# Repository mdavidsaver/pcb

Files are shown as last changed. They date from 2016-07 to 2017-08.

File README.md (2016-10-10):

Arduino Shield w/ iCE40 FPGA
============================

State: Development

ice40 chip used with 3.3V I/O pins and 1.2V core.
Chip is *not* 5V tolerant.

The logic level shifter chips have both 5V and 3.3V.
The TI 74LVC chips require that VCCA by power up
before, or with, VCCB.

All level shifters VCCA==3.3, VCCB==5

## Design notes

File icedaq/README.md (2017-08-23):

iceDAQ
======

Spec.

* 2x DAC
* 2x ADC
* 4x DIO
* SPI interface to controller
* Raspberry Pi Hat
* iCE40 FPGA

Connections to iCE40 FPGA
-------------------------

Programming interface for iCE40 is attached to SPI1 of CPU.  Low speed SPI1 used to configure FPGA, and for debugging of primary interface.  Uses SPI1_CE2 pin to simplify layout.

iCE40 reset and configuration done connected to GPIO pins.

Application program uses SPI0 of CPU to arbitrary I/O pins of iCE40.  Use SPI0_CE0.

i2c eeprom for rpi hat discovery.

Route global clocks 0 and 1 from CPU to iCE40 global inputs

External crystal oscillator connected to iCE40 global input.

Break out UART0 for no particular reason.

Additional SPI connections to 2x ADC and 2x DAC chips.

Break out 4x GPIO pins to header

Analog output
-------------

Use 2x TI DACx311 series SPI DAC.

Operate w/ 3.3V supply.  Could use 5V supply directly as SPI is MOSI only.

output into opamp in non-inverting topology.  Gain=1.5 gives output range of 0-5V from 0-3.3V input.

opamp output has space for series and ground termination.

Analog input
------------

Use 3x TI ADC082S021 (50 KS/S -> 200 KS/S) two channel ADC.  Only one channel per chip used.

Operate w/ 3.3V supply.

input from opamp in non-inverting topology through 0.66 resistor divider (5V -> 3.3V).
opamp gain=1.

input of opamp has space for series and ground termination, also option of AC coupling w/ resistor bias network.

Op Amp
------

Microchip MCP6001 quad rail-to-rail opamp.

Operate w/ 5V supply.

Power budget
------------

Maximum current consumption

3.3V

* iCE40

  <8mA per I/O driver

* eeprom Microchip 24LC23

  <3mA

* 2x DACx311

  short circuit output current @3V = 20mA, @5V = 50mA.

* 2x ADC

  <20mA

* oscillator
* 1.2V regulator

5V

* opamp MCP6001

  <=30 mA
  short circuit output current @1.8V = 6mA, @5.5V = 23 mA

1.2V

* iCE40

  <1mA continuous
  <20mA peak startup

Safety
------

MCP6001 outputs may be shorted w/o damage.  input voltage must be within 1V of supply range.

References
----------

Raspberry Pi

https://github.com/raspberrypi/hats/blob/master/designguide.md

https://pinout.xyz/

https://www.raspberrypi.org/documentation/hardware/raspberrypi/schematics/RPI-3B-V1_2-SCHEMATIC-REDUCED.pdf

iCE40

http://www.latticesemi.com/~/media/LatticeSemi/Documents/Handbooks/iCE40FamilyHandbook.pdf

ADC

http://www.ti.com/lit/ds/symlink/adc082s021.pdf

DAC

http://www.ti.com/lit/ds/symlink/dac5311.pdf

opamp

http://ww1.microchip.com/downloads/en/DeviceDoc/21733j.pdf

eeprom

http://ww1.microchip.com/downloads/en/DeviceDoc/21072G.pdf

iCE40 pins
----------

set_io	GPIO2[0]	1
set_io	GPIO2[1]	2
set_io	GPIO2[2]	3
set_io	GPIO2[3]	4
set_io	GPIO3[0]	18
set_io	GPIO3[1]	19
set_io	GPIO3[2]	20
set_io	GPIO3[3]	21
set_io	GPIO0[3]	27
set_io	GPIO0[2]	28
set_io	GPIO0[1]	29
set_io	GPIO0[0]	30
set_io	GCLK0	33
set_io	GCLK1	34
set_io	SPI1_MISO	45
set_io	SPI1_MOSI	46
set_io	SPI1_SCK	48
set_io	SPI1_CE2	49
set_io	SPI0_CE0	51
set_io	SPI0_SCLK	52
set_io	SPI0_MISO	53
set_io	SPI0_MOSI	54
set_io	ADC0_CE	56
set_io	ADC0_SCK	57
set_io	ADC0_MISO	59
set_io	ADC0_MOSI	60
set_io	ADC1_CE	64
set_io	ADC1_SCK	65
set_io	ADC1_MISO	66
set_io	ADC1_MOSI	68
set_io	DAC0_MOSI	78
set_io	DAC0_SCK	79
set_io	DAC0_SYNC	80
set_io	DAC1_MOSI	82
set_io	DAC1_SCK	83
set_io	DAC1_SYNC	85
set_io	CLK	90

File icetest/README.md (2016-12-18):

Arduino Shield w/ iCE40 FPGA
============================

State: Rev 2 tested

[Firmware](https://github.com/mdavidsaver/fpga/tree/master/top/icetest_r2)
[Software](https://github.com/mdavidsaver/fpga/tree/master/avr)

Erratta for rev. 2

* Add pull-up on SS
* LP filter/ isolation on SPI line (noticable cross-talk)

ice40 chip used with 3.3V I/O pins and 1.2V core.
Chip is *not* 5V tolerant.

The logic level shifter chips have both 5V and 3.3V.
The TI 74LVC chips require that VCCA by power up
before, or with, VCCB.

All level shifters VCCA==3.3, VCCB==5

Strictly speaking level shifters not needed for 3.3V -> 5V.

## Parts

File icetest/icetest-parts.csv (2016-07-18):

Comment | Manufacturer | Digikey | Price | Num |  | URL
fpga | ICE40HX1K-VQ100 | 220-1567-ND | $4.95 | 1 | $4.95 | http://www.digikey.com/product-detail/en/lattice-semiconductor-corporation/ICE40HX1K-VQ100/220-1567-ND/3083577
level translate | TXB0108PWR | 296-21527-1-ND | $1.88 | 4 | $7.52 | http://www.digikey.com/product-detail/en/texas-instruments/TXB0108PWR/296-21527-1-ND/1305700
1.2V reg. | NCP585DSN12T1G | NCP585DSN12T1GOSCT-ND | $0.71 | 1 | $0.71 | http://www.digikey.com/product-detail/en/on-semiconductor/NCP585DSN12T1G/NCP585DSN12T1GOSCT-ND/822802
3.3V reg. | AP2112K-3.3TRG1 | AP2112K-3.3TRG1DICT-ND | $0.48 | 1 | $0.48 | http://www.digikey.com/product-detail/en/diodes-incorporated/AP2112K-3.3TRG1/AP2112K-3.3TRG1DICT-ND/4505257
20V shottky diode | CDBU0520 | 641-1332-1-ND | $0.47 | 1 | $0.47 | http://www.digikey.com/product-detail/en/comchip-technology/CDBU0520/641-1332-1-ND/2021253
12MHz Osc. | 636L3C012M00000 | CTX1006CT-ND | $1.37 | 1 | $1.37 | http://www.digikey.com/product-detail/en/cts-frequency-controls/636L3C012M00000/CTX1006CT-ND/2640344
 |  |  |  |  | $15.50

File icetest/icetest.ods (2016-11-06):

Comment | Manufacturer | Digikey | Price | Num |  | URL
fpga | ICE40HX1K-VQ100 | 220-1567-ND | $4.95 | 1 | $4.95 | http://www.digikey.com/product-detail/en/lattice-semiconductor-corporation/ICE40HX1K-VQ100/220-1567-ND/3083577
level translate | SN74LVC2T45 | 568-5479-1-ND | $0.58 | 8 | $4.64 | http://www.nxp.com/documents/data_sheet/74LVC_LVCH2T45.pdf
level translate | TXB0108PWR | 296-21527-1-ND | $1.80 | 0 | $0.00 | http://www.digikey.com/product-detail/en/texas-instruments/TXB0108PWR/296-21527-1-ND/1305700
1.2V reg. | NCP585DSN12T1G | NCP585DSN12T1GOSCT-ND | $0.71 | 1 | $0.71 | http://www.digikey.com/product-detail/en/on-semiconductor/NCP585DSN12T1G/NCP585DSN12T1GOSCT-ND/822802
3.3V reg. | AP2112K-3.3TRG1 | AP2112K-3.3TRG1DICT-ND | $0.48 | 1 | $0.48 | http://www.digikey.com/product-detail/en/diodes-incorporated/AP2112K-3.3TRG1/AP2112K-3.3TRG1DICT-ND/4505257
20V shottky diode | CDBU0520 | 641-1332-1-ND | $0.47 | 1 | $0.47 | http://www.digikey.com/product-detail/en/comchip-technology/CDBU0520/641-1332-1-ND/2021253
12MHz Osc. | 636L3C012M00000 | CTX1006CT-ND | $1.37 | 1 | $1.37 | http://www.digikey.com/product-detail/en/cts-frequency-controls/636L3C012M00000/CTX1006CT-ND/2640344
22 ohm resitor |  |  | $0.01 | 6 | $0.06
10k resistor | RC0603FR-0710KL | 311-10.0KHRCT-ND | $0.01 | 11 | $0.11 | http://www.digikey.com/product-detail/en/yageo/RC0603FR-0710KL/311-10.0KHRCT-ND/729827
1u cap |  |  | $0.04 | 5 | $0.20
100n cap |  | 490-1519-1-ND | $0.04 | 16 | $0.64 | http://www.digikey.com/product-detail/en/murata-electronics-north-america/GRM188R71H104KA93D/490-1519-1-ND/587854
LED |  |  | $0.10 | 2 | $0.20
Pin header 0.1mil |  |  |  | 96 | $0.00
 |  |  |  |  | $12.62

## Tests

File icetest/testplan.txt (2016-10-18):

* Populate 1.2v and 3.3v regulators and test w/ standalone 5v supply.
  * All voltages accessible from top side

* Populate UL1, 2, and 3 and test level shifting
  * Test pads for all 6 control lines

* Populate ICE1 and test bit stream load
  * AVR program to load via. SPI
  * .v to loop back MOSI to MISO and D9 to D8 (RST -> CDONE)

* Populate OSC1 and check frequency
  * copy OSC1 to output pin(s)

* Populate LEDs, UL4 and test
  * copy D5,6 to LED outputs, drive with AVR PWM

* Populate UL5, 6, 7, 8 and test 5V from ICE1
  * copy D5,6 to outputs

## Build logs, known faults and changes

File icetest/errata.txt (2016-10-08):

rev1 issues

* Need 1.2V test points on top side.
* Would be good to mark ARD pins on top side.

* bus transceiver not working so easily.  Probably needed to put pull ups on driving side...

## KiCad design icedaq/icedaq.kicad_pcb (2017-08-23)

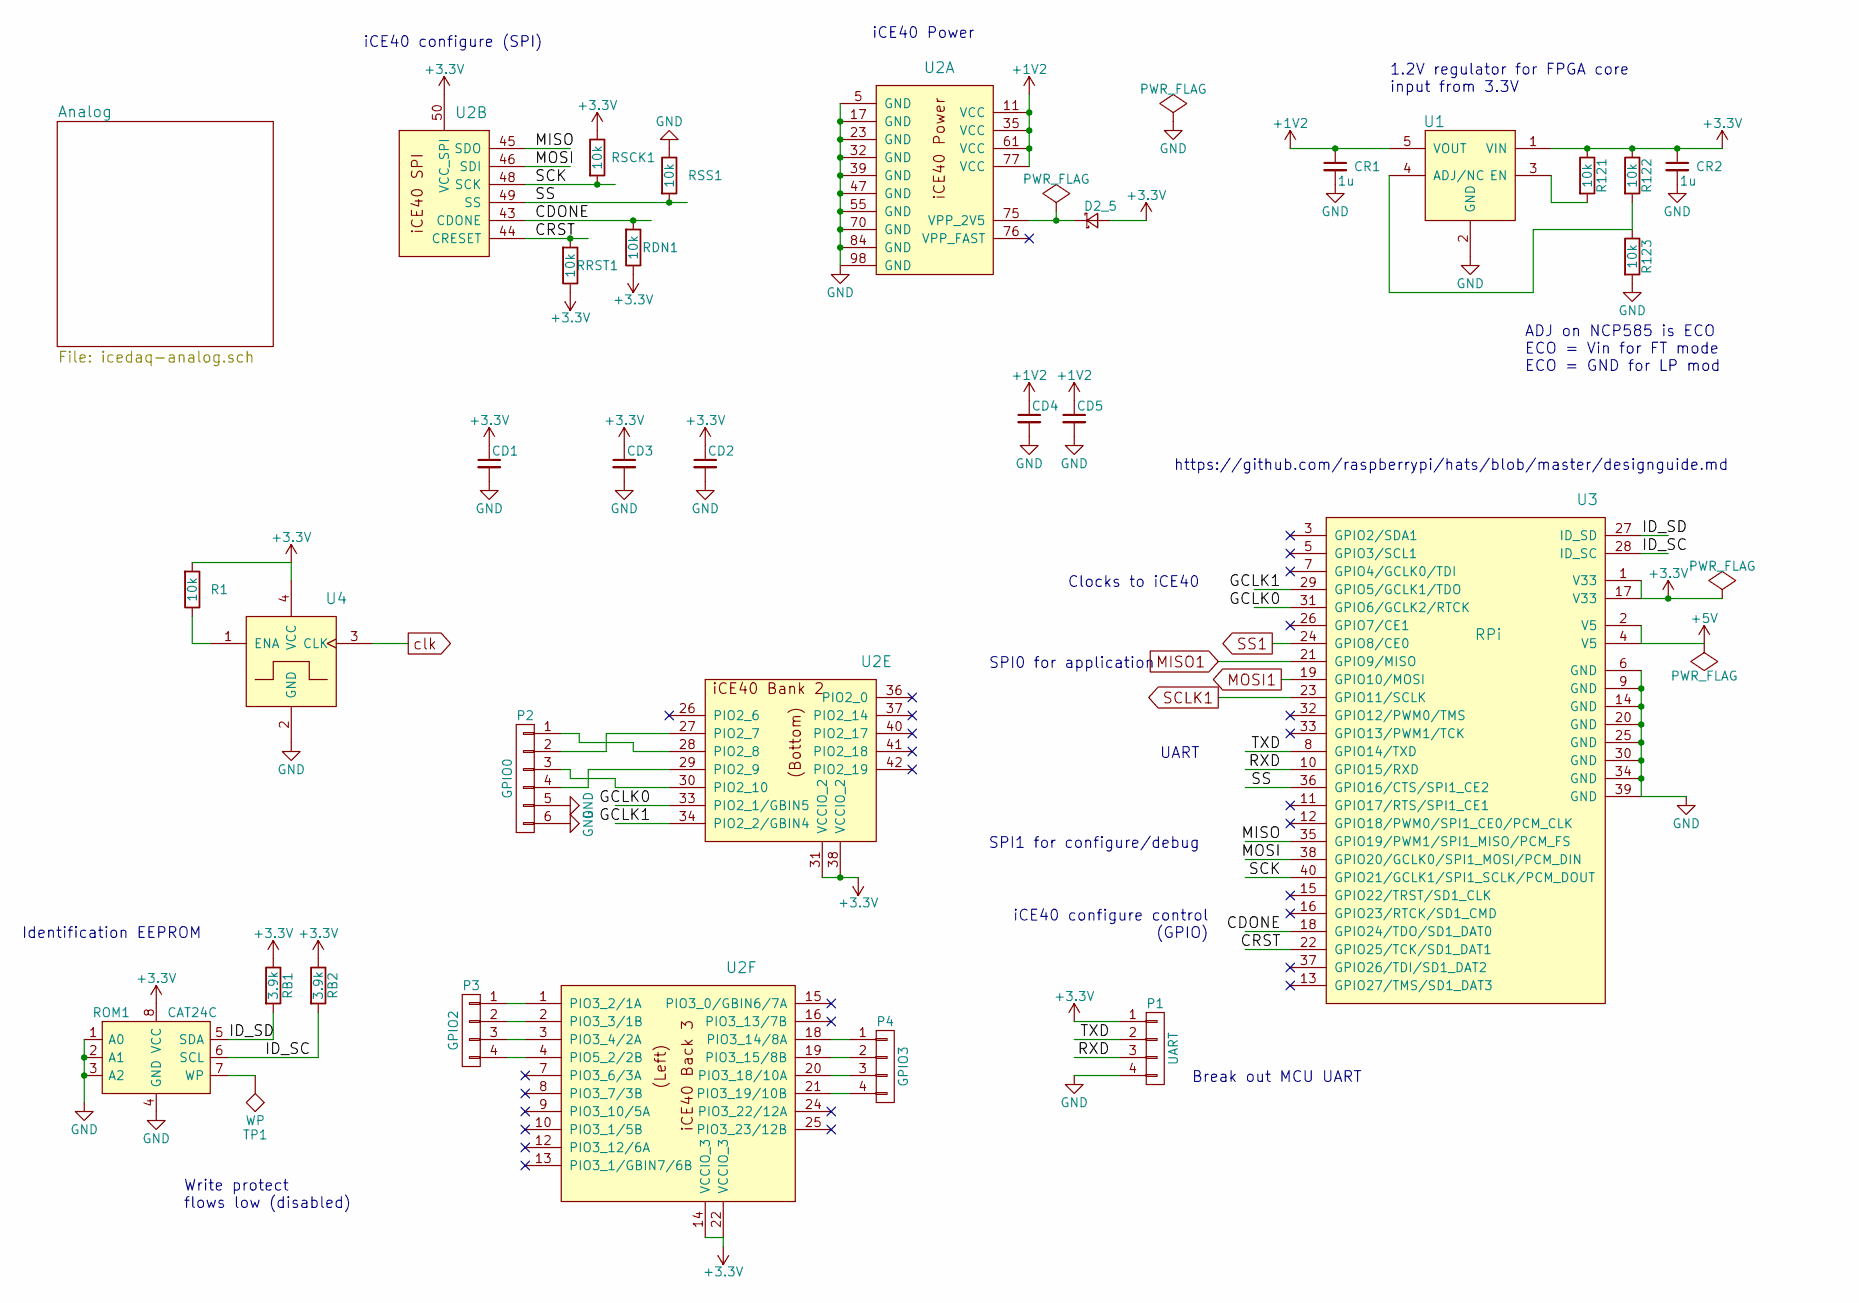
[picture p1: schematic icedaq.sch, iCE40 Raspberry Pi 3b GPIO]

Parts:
CD1, CD2, CD3, CD4, CD5: C_Small; C_0603_HandSoldering
CR1, CR2: 1u; C_0603_HandSoldering
D2_5: D_Schottky_Small; D_0603_HandSoldering
P1: UART; Pin_Header_Straight_1x04
P2: GPIO0; Pin_Header_Straight_2x03
P3: GPIO2; gpio
P4: GPIO3; gpio
R1, R121, R122, R123: 10k; R_0603_HandSoldering
RB1, RB2: 3.9k; R_0603_HandSoldering
RDN1: 10k; R_0603_HandSoldering
ROM1: CAT24C; SOIC-8_3.9x4.9mm_Pitch1.27mm
RRST1: 10k; R_0603_HandSoldering
RSCK1: 10k; R_0603_HandSoldering
RSS1: 10k; R_0603_HandSoldering
TP1: WP; testpoint
U1: REG12; SOT23-5
U2: iCE40HX1K-VQ100; VQFP-100
U3: RPi; Pin_Header_Straight_2x20
U4: oscillator4; OSC_SMD_1

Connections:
+1V2: CD4.1, CD5.1, CR1.1, U1.5 (VOUT), U2.11 (VCC), U2.35 (VCC), U2.61 (VCC), U2.77 (VCC)
+3V3: CD1.1, CD2.1, CD3.1, CR2.1, D2_5.2 (A), P1.1, R1.2, R121.1, R122.1, RB1.1, RB2.1, RDN1.1, ROM1.8 (VCC), RRST1.1, RSCK1.1, U1.1 (VIN), U2.14 (VCCIO_3), U2.22 (VCCIO_3), U2.31 (VCCIO_2), U2.38 (VCCIO_2), U2.50 (VCC_SPI), U3.1 (V33), U3.17 (V33), U4.4 (VCC); also elsewhere on the board
+5V: U3.2 (V5), U3.4 (V5); also elsewhere on the board
/CDONE: RDN1.2, U2.43 (CDONE), U3.18 (GPIO24/TDO/SD1_DAT0)
/CRST: RRST1.2, U2.44 (CRESET), U3.22 (GPIO25/TCK/SD1_DAT1)
/GCLK0: U2.33 (PIO2_1/GBIN5), U3.31 (GPIO6/GCLK2/RTCK)
/GCLK1: U2.34 (PIO2_2/GBIN4), U3.29 (GPIO5/GCLK1/TDO)
/ID_SC: RB2.2, ROM1.6 (SCL), U3.28 (ID_SC)
/ID_SD: RB1.2, ROM1.5 (SDA), U3.27 (ID_SD)
/MISO: U2.45 (SDO), U3.35 (GPIO19/PWM1/SPI1_MISO/PCM_FS)
/MOSI: U2.46 (SDI), U3.38 (GPIO20/GCLK0/SPI1_MOSI/PCM_DIN)
/RXD: P1.3, U3.10 (GPIO15/RXD)
/SCK: RSCK1.2, U2.48 (SCK), U3.40 (GPIO21/GCLK1/SPI1_SCLK/PCM_DOUT)
/SS: RSS1.2, U2.49 (SS), U3.36 (GPIO16/CTS/SPI1_CE2)
/TXD: P1.2, U3.8 (GPIO14/TXD)
GND: CD1.2, CD2.2, CD3.2, CD4.2, CD5.2, CR1.2, CR2.2, P1.4, P2.5, P2.6, R123.2, ROM1.1 (A0), ROM1.2 (A1), ROM1.3 (A2), ROM1.4 (GND), RSS1.1, U1.2 (GND), U2.5 (GND), U2.17 (GND), U2.23 (GND), U2.32 (GND), U2.39 (GND), U2.47 (GND), U2.55 (GND), U2.70 (GND), U2.84 (GND), U2.98 (GND), U3.6 (GND), U3.9 (GND), U3.14 (GND), U3.20 (GND), U3.25 (GND), U3.30 (GND), U3.34 (GND), U3.39 (GND), U4.2 (GND); also elsewhere on the board
MISO1: U3.21 (GPIO9/MISO); also elsewhere on the board
MOSI1: U3.19 (GPIO10/MOSI); also elsewhere on the board
unnamed: D2_5.1 (K), U2.75 (VPP_2V5)
unnamed: P2.1, U2.28 (PIO2_8)
unnamed: P2.2, U2.27 (PIO2_7)
unnamed: P2.3, U2.30 (PIO2_10)
unnamed: P2.4, U2.29 (PIO2_9)
unnamed: P3.1, U2.1 (PIO3_2/1A)
unnamed: P3.2, U2.2 (PIO3_3/1B)
unnamed: P3.3, U2.3 (PIO3_4/2A)
unnamed: P3.4, U2.4 (PIO5_2/2B)
unnamed: P4.1, U2.18 (PIO3_14/8A)
unnamed: P4.2, U2.19 (PIO3_15/8B)
unnamed: P4.3, U2.20 (PIO3_18/10A)
unnamed: P4.4, U2.21 (PIO3_19/10B)
unnamed: R1.1, U4.1 (ENA)
unnamed: R121.2, U1.3 (EN)
unnamed: R122.2, R123.1, U1.4 (ADJ/NC)
unnamed: ROM1.7 (WP), TP1.1
SCLK1: U3.23 (GPIO11/SCLK); also elsewhere on the board
SS1: U3.24 (GPIO8/CE0); also elsewhere on the board
clk: U4.3 (CLK); also elsewhere on the board

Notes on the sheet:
1.2V regulator for FPGA core input from 3.3V
ADJ on NCP585 is ECO ECO = Vin for FT mode ECO = GND for LP mod
SPI0 for application
SPI1 for configure/debug
iCE40 configure control (GPIO)
UART
Clocks to iCE40
iCE40 Power
iCE40 configure (SPI)
https://github.com/raspberrypi/hats/blob/master/designguide.md
Break out MCU UART
Write protect flows low (disabled)
Identification EEPROM

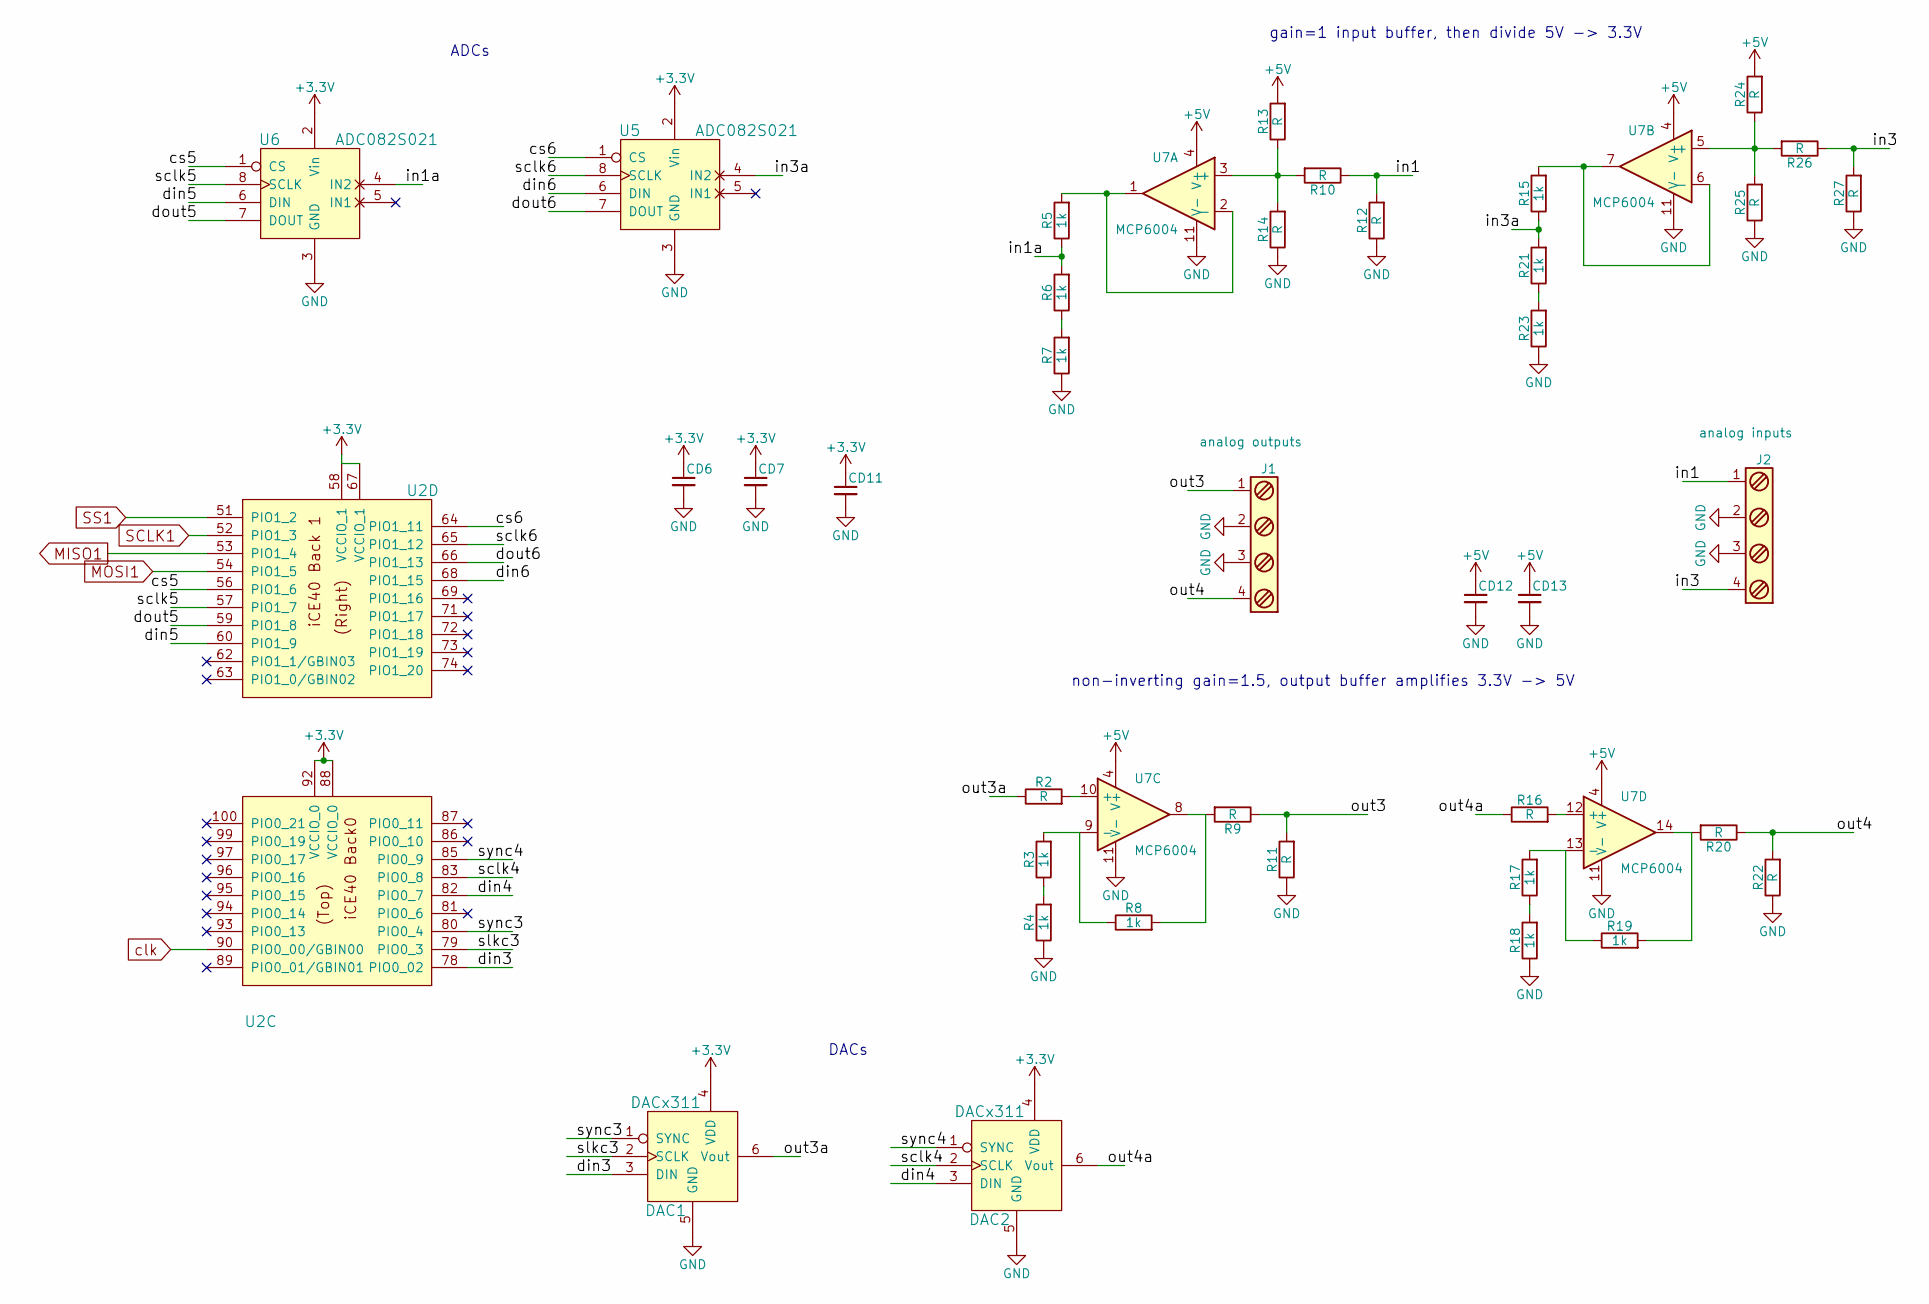
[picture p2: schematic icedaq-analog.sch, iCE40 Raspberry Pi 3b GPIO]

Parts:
CD6, CD7, CD11, CD12, CD13: C_Small; C_0603_HandSoldering
DAC1, DAC2: DACx311; SC70
J1: analog outputs; TerminalBlock_Pheonix_MPT-2.54mm_4pol
J2: analog inputs; TerminalBlock_Pheonix_MPT-2.54mm_4pol
R2, R9, R10, R11, R12, R13, R14, R16, R20, R22, R24, R25, R26, R27: R; R_0603_HandSoldering
R3, R4, R5, R6, R7, R8, R15, R17, R18, R19, R21, R23: 1k; R_0603_HandSoldering
U2: iCE40HX1K-VQ100; VQFP-100
U5, U6: ADC082S021; VSSOP-8
U7: MCP6004; SOIC-14

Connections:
+3V3: CD6.1, CD7.1, CD11.1, DAC1.4 (VDD), DAC2.4 (VDD), U2.58 (VCCIO_1), U2.67 (VCCIO_1), U2.88 (VCCIO_0), U2.92 (VCCIO_0), U5.2 (Vin), U6.2 (Vin); also elsewhere on the board
+5V: CD12.1, CD13.1, R13.2, R24.2, U7.4 (V+); also elsewhere on the board
/Analog/cs5: U2.56 (PIO1_6), U6.1 (CS)
/Analog/cs6: U2.64 (PIO1_11), U5.1 (CS)
/Analog/din3: DAC1.3 (DIN), U2.78 (PIO0_02)
/Analog/din4: DAC2.3 (DIN), U2.82 (PIO0_7)
/Analog/din5: U2.60 (PIO1_9), U6.6 (DIN)
/Analog/din6: U2.68 (PIO1_15), U5.6 (DIN)
/Analog/dout5: U2.59 (PIO1_8), U6.7 (DOUT)
/Analog/dout6: U2.66 (PIO1_13), U5.7 (DOUT)
/Analog/in1: J2.1, R10.1, R12.2
/Analog/in1a: R5.1, R6.2, U6.4 (IN2)
/Analog/in3: J2.4, R26.1, R27.2
/Analog/in3a: R15.1, R21.2, U5.4 (IN2)
/Analog/out3: J1.1, R9.1, R11.2
/Analog/out3a: DAC1.6 (Vout), R2.1
/Analog/out4: J1.4, R20.1, R22.2
/Analog/out4a: DAC2.6 (Vout), R16.1
/Analog/sclk4: DAC2.2 (SCLK), U2.83 (PIO0_8)
/Analog/sclk5: U2.57 (PIO1_7), U6.8 (SCLK)
/Analog/sclk6: U2.65 (PIO1_12), U5.8 (SCLK)
/Analog/slkc3: DAC1.2 (SCLK), U2.79 (PIO0_3)
/Analog/sync3: DAC1.1 (SYNC), U2.80 (PIO0_4)
/Analog/sync4: DAC2.1 (SYNC), U2.85 (PIO0_9)
GND: CD6.2, CD7.2, CD11.2, CD12.2, CD13.2, DAC1.5 (GND), DAC2.5 (GND), J1.2, J1.3, J2.2, J2.3, R4.1, R7.1, R11.1, R12.1, R14.1, R18.1, R22.1, R23.1, R25.1, R27.1, U5.3 (GND), U6.3 (GND), U7.11 (V-); also elsewhere on the board
MISO1: U2.53 (PIO1_4); also elsewhere on the board
MOSI1: U2.54 (PIO1_5); also elsewhere on the board
unnamed: R2.2, U7.10 (+)
unnamed: R3.1, R4.2
unnamed: R3.2, R8.1, U7.9 (-)
unnamed: R5.2, U7.1, U7.2 (-)
unnamed: R6.1, R7.2
unnamed: R8.2, R9.2, U7.8
unnamed: R10.2, R13.1, R14.2, U7.3 (+)
unnamed: R15.2, U7.6 (-), U7.7
unnamed: R16.2, U7.12 (+)
unnamed: R17.1, R18.2
unnamed: R17.2, R19.1, U7.13 (-)
unnamed: R19.2, R20.2, U7.14
unnamed: R21.1, R23.2
unnamed: R24.1, R25.2, R26.2, U7.5 (+)
SCLK1: U2.52 (PIO1_3); also elsewhere on the board
SS1: U2.51 (PIO1_2); also elsewhere on the board
clk: U2.90 (PIO0_00/GBIN00); also elsewhere on the board

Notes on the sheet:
gain=1 input buffer, then divide 5V -> 3.3V
non-inverting gain=1.5, output buffer amplifies 3.3V -> 5V
ADCs
DACs

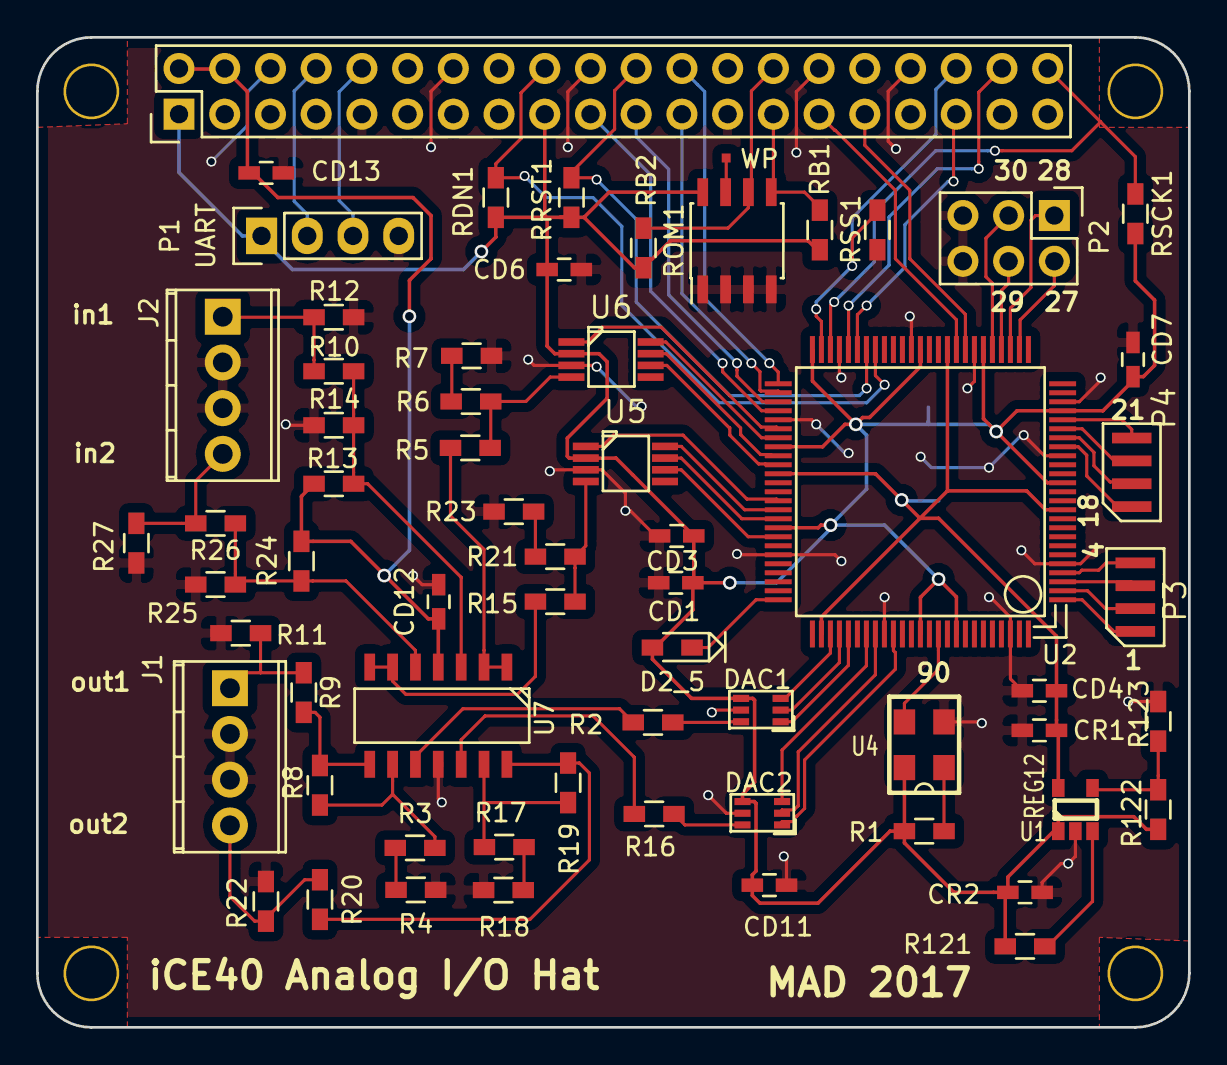
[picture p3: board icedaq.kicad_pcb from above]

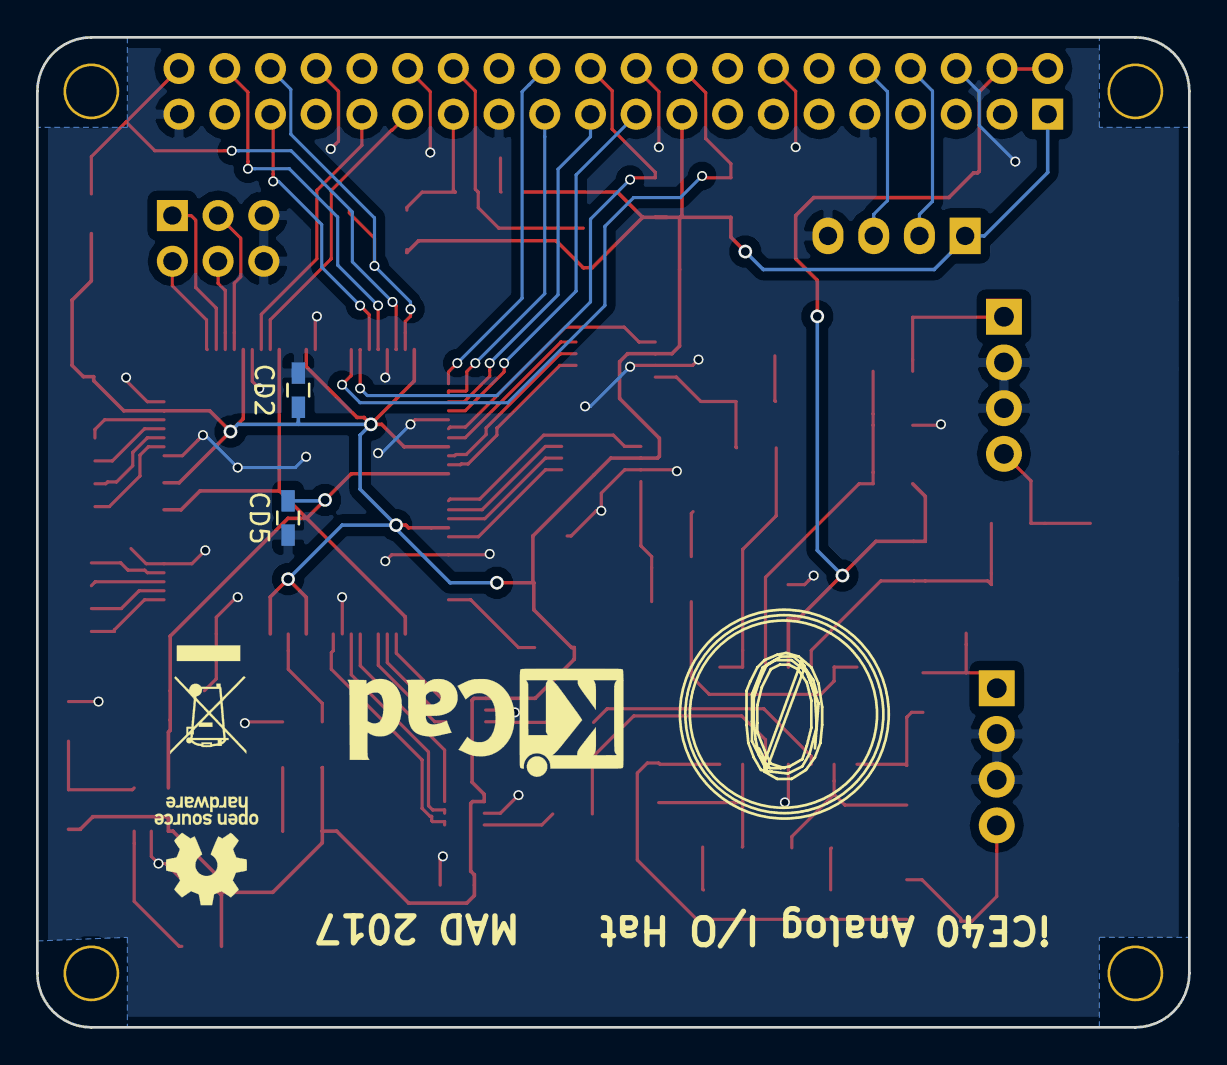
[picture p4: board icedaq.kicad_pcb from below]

Board: 2 copper layers, 64.0 x 55.0 mm, 67 parts (2 on the bottom side), 74 nets.

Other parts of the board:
MNT1: MountingHole_3mm

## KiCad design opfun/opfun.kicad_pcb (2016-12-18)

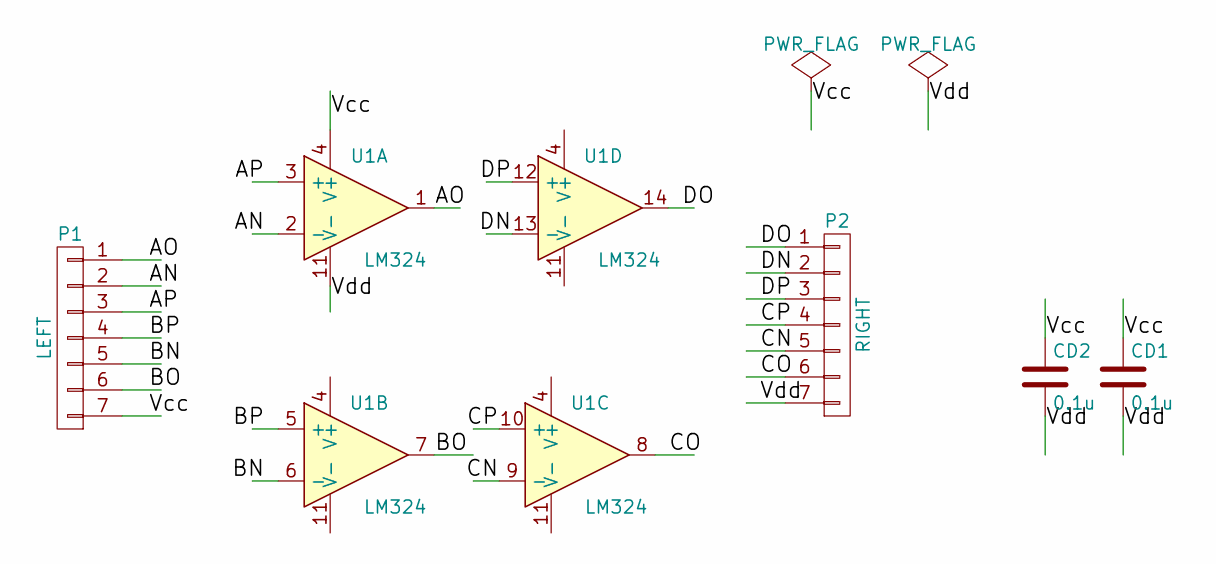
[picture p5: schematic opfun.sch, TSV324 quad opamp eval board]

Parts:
CD1, CD2: 0.1u; C_0603_HandSoldering
P1: LEFT; Pin_Header_Straight_1x07
P2: RIGHT; Pin_Header_Straight_1x07
U1: LM324; TSSOP-14

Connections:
/AN: P1.2, U1.2 (-)
/AO: P1.1, U1.1
/AP: P1.3, U1.3 (+)
/BN: P1.5, U1.6 (-)
/BO: P1.6, U1.7
/BP: P1.4, U1.5 (+)
/CN: P2.5, U1.9 (-)
/CO: P2.6, U1.8
/CP: P2.4, U1.10 (+)
/DN: P2.2, U1.13 (-)
/DO: P2.1, U1.14
/DP: P2.3, U1.12 (+)
/Vcc: CD1.1, CD2.1, P1.7, U1.4 (V+)
/Vdd: CD1.2, CD2.2, P2.7, U1.11 (V-)

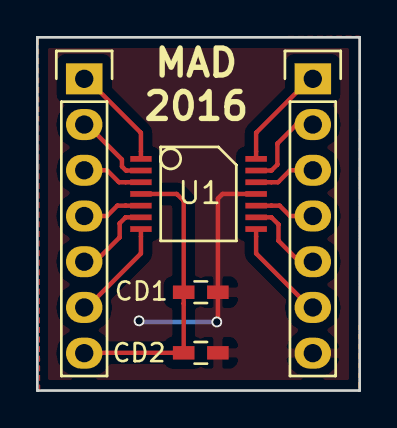
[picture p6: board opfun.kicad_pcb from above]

Board: 2 copper layers, 17.9 x 19.6 mm, 5 parts (0 on the bottom side), 14 nets.

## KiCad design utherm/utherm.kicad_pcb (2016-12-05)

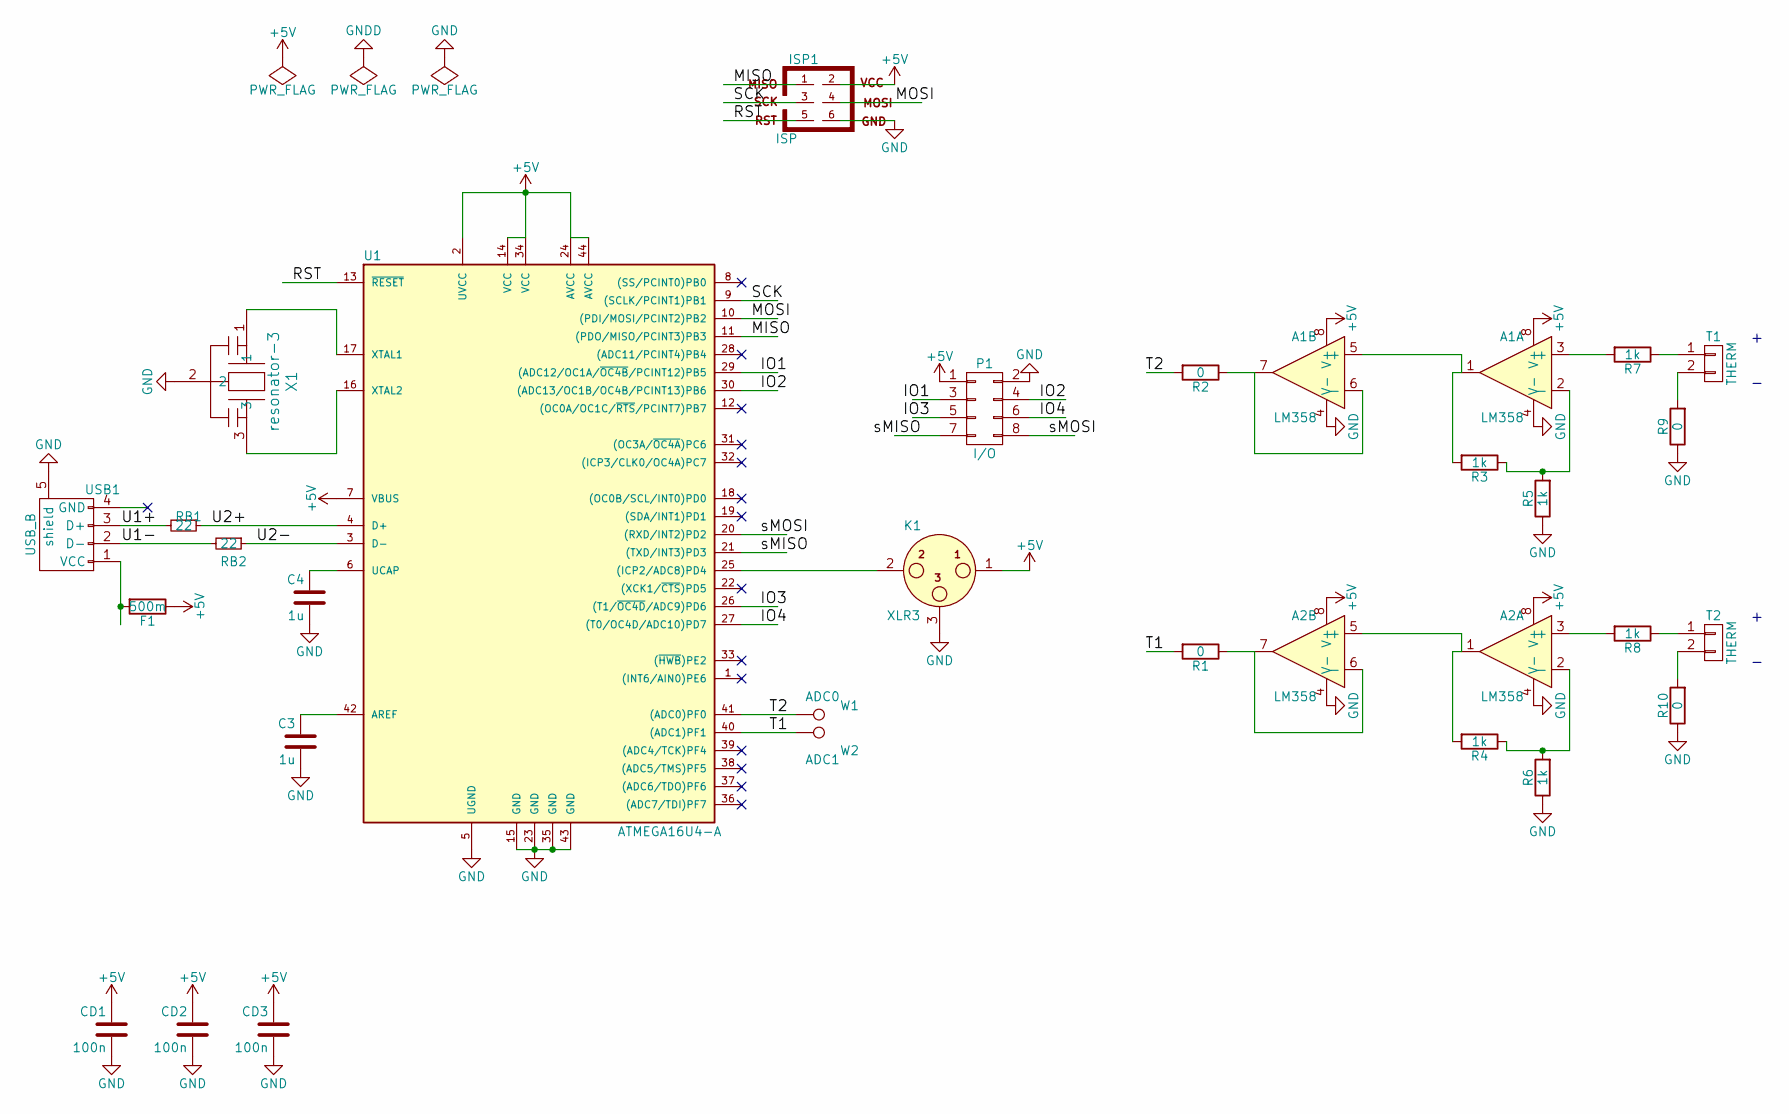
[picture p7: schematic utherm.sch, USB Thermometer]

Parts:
A1, A2: LM358; SO8_6mm
C3, C4: 1u; C_0603_HandSoldering
CD1, CD2, CD3: 100n; C_0603_HandSoldering
F1: 500m; R_1218_HandSoldering
ISP1: ISP; Pin_Header_Straight_2x03
K1: XLR3; TO-92_Molded_Narrow
P1: I/O; Pin_Header_Straight_2x04
R1, R2, R9, R10: 0; R_0603_HandSoldering
R3, R4, R5, R6, R7, R8: 1k; R_0603_HandSoldering
RB1, RB2: 22; R_0603_HandSoldering
T1, T2: THERM; TerminalBlock_Pheonix_MKDS1.5-2pol
U1: ATMEGA16U4-A; TQFP44
USB1: USB_B; USB_B_micro
W1: ADC0; Measurement_Point_Square-SMD-Pad_Small
W2: ADC1; Measurement_Point_Square-SMD-Pad_Small
X1: resonator-3

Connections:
+5V: A1.8 (V+), A2.8 (V+), CD1.1, CD2.1, CD3.1, F1.1, ISP1.2, K1.1, P1.1, U1.2 (UVCC), U1.7 (VBUS), U1.14 (VCC), U1.24 (AVCC), U1.34 (VCC), U1.44 (AVCC)
/IO1: P1.3, U1.29 ((ADC12/OC1A/~OC4B~/PCINT12)PB5)
/IO2: P1.4, U1.30 ((ADC13/OC1B/OC4B/PCINT13)PB6)
/IO3: P1.5, U1.26 ((T1/~OC4D~/ADC9)PD6)
/IO4: P1.6, U1.27 ((T0/OC4D/ADC10)PD7)
/MISO: ISP1.1, U1.11 ((PDO/MISO/PCINT3)PB3)
/MOSI: ISP1.4, U1.10 ((PDI/MOSI/PCINT2)PB2)
/RST: ISP1.5, U1.13 (~RESET~)
/SCK: ISP1.3, U1.9 ((SCLK/PCINT1)PB1)
/T1: R1.2, U1.40 ((ADC1)PF1), W2.1
/T2: R2.2, U1.41 ((ADC0)PF0), W1.1
/U1+: RB1.2, USB1.3 (D+)
/U1-: RB2.2, USB1.2 (D-)
/U2+: RB1.1, U1.4 (D+)
/U2-: RB2.1, U1.3 (D-)
/sMISO: P1.7, U1.21 ((TXD/INT3)PD3)
/sMOSI: P1.8, U1.20 ((RXD/INT2)PD2)
GND: A1.4 (V-), A2.4 (V-), C3.2, C4.2, CD1.2, CD2.2, CD3.2, ISP1.6, K1.3, P1.2, R5.1, R6.1, R9.1, R10.1, U1.5 (UGND), U1.15 (GND), U1.23 (GND), U1.35 (GND), U1.43 (GND), USB1.5 (shield), X1.2
unnamed: A1.1, A1.5 (+), R3.2
unnamed: A1.2 (-), R3.1, R5.2
unnamed: A1.3 (+), R7.2
unnamed: A1.6 (-), A1.7, R2.1
unnamed: A2.1, A2.5 (+), R4.2
unnamed: A2.2 (-), R4.1, R6.2
unnamed: A2.3 (+), R8.2
unnamed: A2.6 (-), A2.7, R1.1
unnamed: C3.1, U1.42 (AREF)
unnamed: C4.1, U1.6 (UCAP)
unnamed: F1.2, USB1.1 (VCC)
unnamed: K1.2, U1.25 ((ICP2/ADC8)PD4)
unnamed: R7.1, T1.1
unnamed: R8.1, T2.1
unnamed: R9.2, T1.2
unnamed: R10.2, T2.2
unnamed: U1.16 (XTAL2), X1.3
unnamed: U1.17 (XTAL1), X1.1

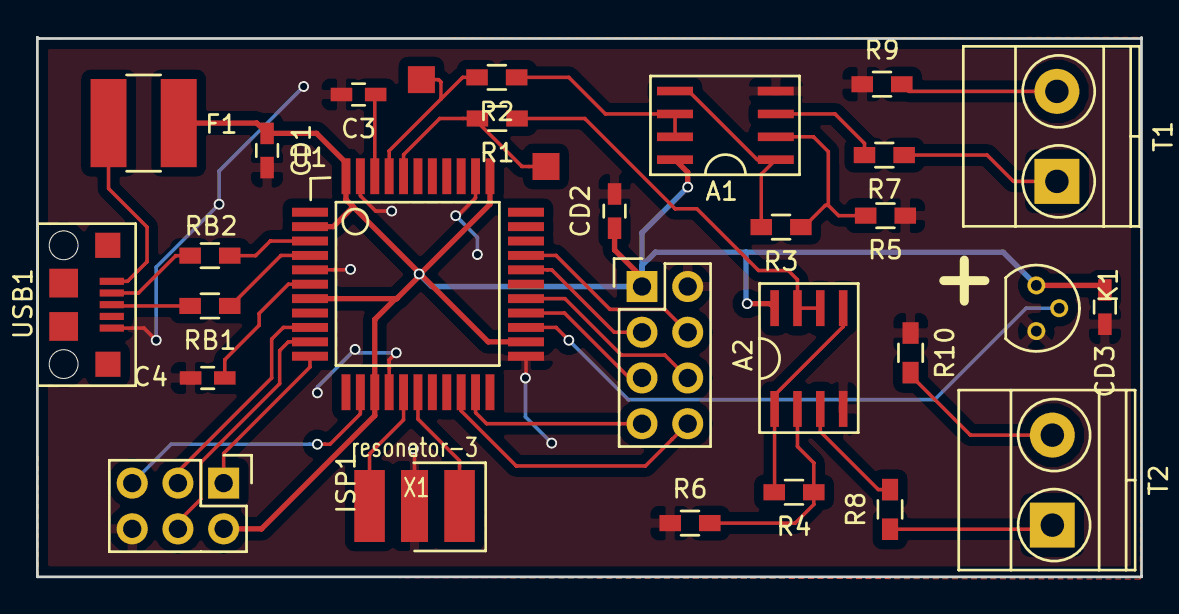
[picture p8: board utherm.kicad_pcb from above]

Board: 2 copper layers, 61.3 x 30.0 mm, 30 parts (0 on the bottom side), 36 nets.

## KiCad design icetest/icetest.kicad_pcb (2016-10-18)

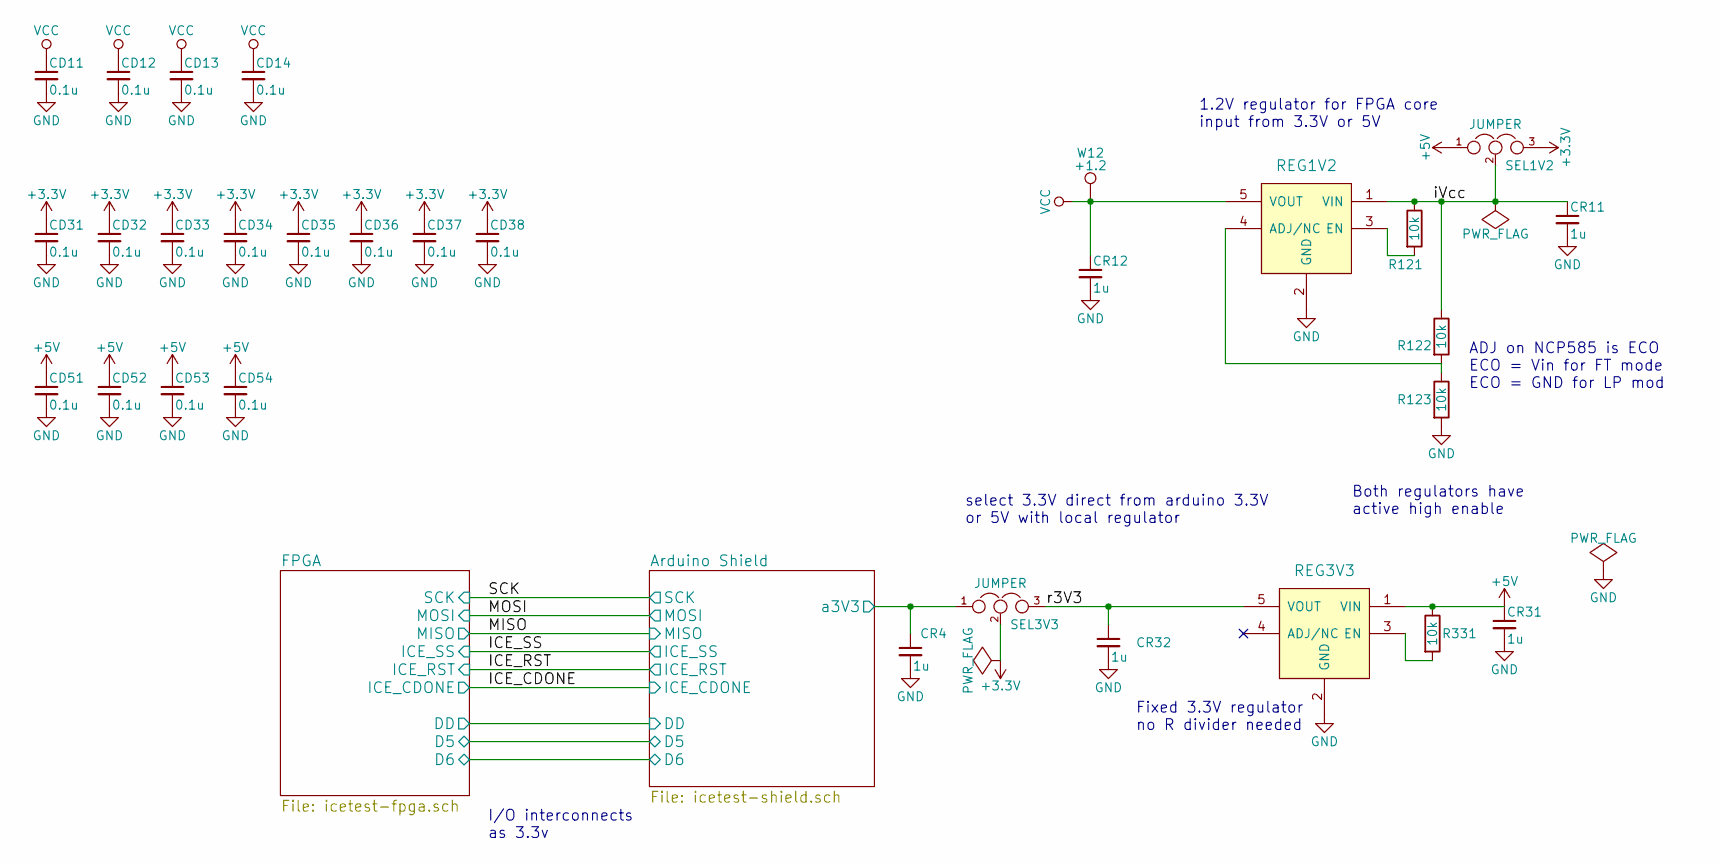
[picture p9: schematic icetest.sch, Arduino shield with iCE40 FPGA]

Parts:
CD11, CD12, CD13, CD14, CD31, CD32, CD33, CD34, CD35, CD36, CD37, CD38, CD51, CD52, CD53, CD54: 0.1u; C_0603_HandSoldering
CR4, CR11, CR12, CR31, CR32: 1u; C_0603_HandSoldering
R121, R122, R123, R331: 10k; R_0603_HandSoldering
REG1V2, REG3V3: regulator5; SOT23-5
SEL1V2, SEL3V3: JUMPER; Pin_Header_Straight_1x03
W12: +1.2; Measurement_Point_Square-SMD-Pad_Small

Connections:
+3V3: CD31.1, CD32.1, CD33.1, CD34.1, CD35.1, CD36.1, CD37.1, CD38.1, SEL1V2.3, SEL3V3.2; also elsewhere on the board
+5V: CD51.1, CD52.1, CD53.1, CD54.1, CR31.1, R331.1, REG3V3.1 (VIN), SEL1V2.1; also elsewhere on the board
/Arduino Shield/a3V3: CR4.1, SEL3V3.1; also elsewhere on the board
/iVcc: CR11.1, R121.1, R122.1, REG1V2.1 (VIN), SEL1V2.2
/r3V3: CR32.1, REG3V3.5 (VOUT), SEL3V3.3
GND: CD11.2, CD12.2, CD13.2, CD14.2, CD31.2, CD32.2, CD33.2, CD34.2, CD35.2, CD36.2, CD37.2, CD38.2, CD51.2, CD52.2, CD53.2, CD54.2, CR4.2, CR11.2, CR12.2, CR31.2, CR32.2, R123.2, REG1V2.2 (GND), REG3V3.2 (GND); also elsewhere on the board
unnamed: R121.2, REG1V2.3 (EN)
unnamed: R122.2, R123.1, REG1V2.4 (ADJ/NC)
unnamed: R331.2, REG3V3.3 (EN)
VCC: CD11.1, CD12.1, CD13.1, CD14.1, CR12.1, REG1V2.5 (VOUT), W12.1; also elsewhere on the board

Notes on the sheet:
select 3.3V direct from arduino 3.3V or 5V with local regulator
1.2V regulator for FPGA core input from 3.3V or 5V
ADJ on NCP585 is ECO ECO = Vin for FT mode ECO = GND for LP mod
Fixed 3.3V regulator no R divider needed
Both regulators have active high enable
I/O interconnects as 3.3v

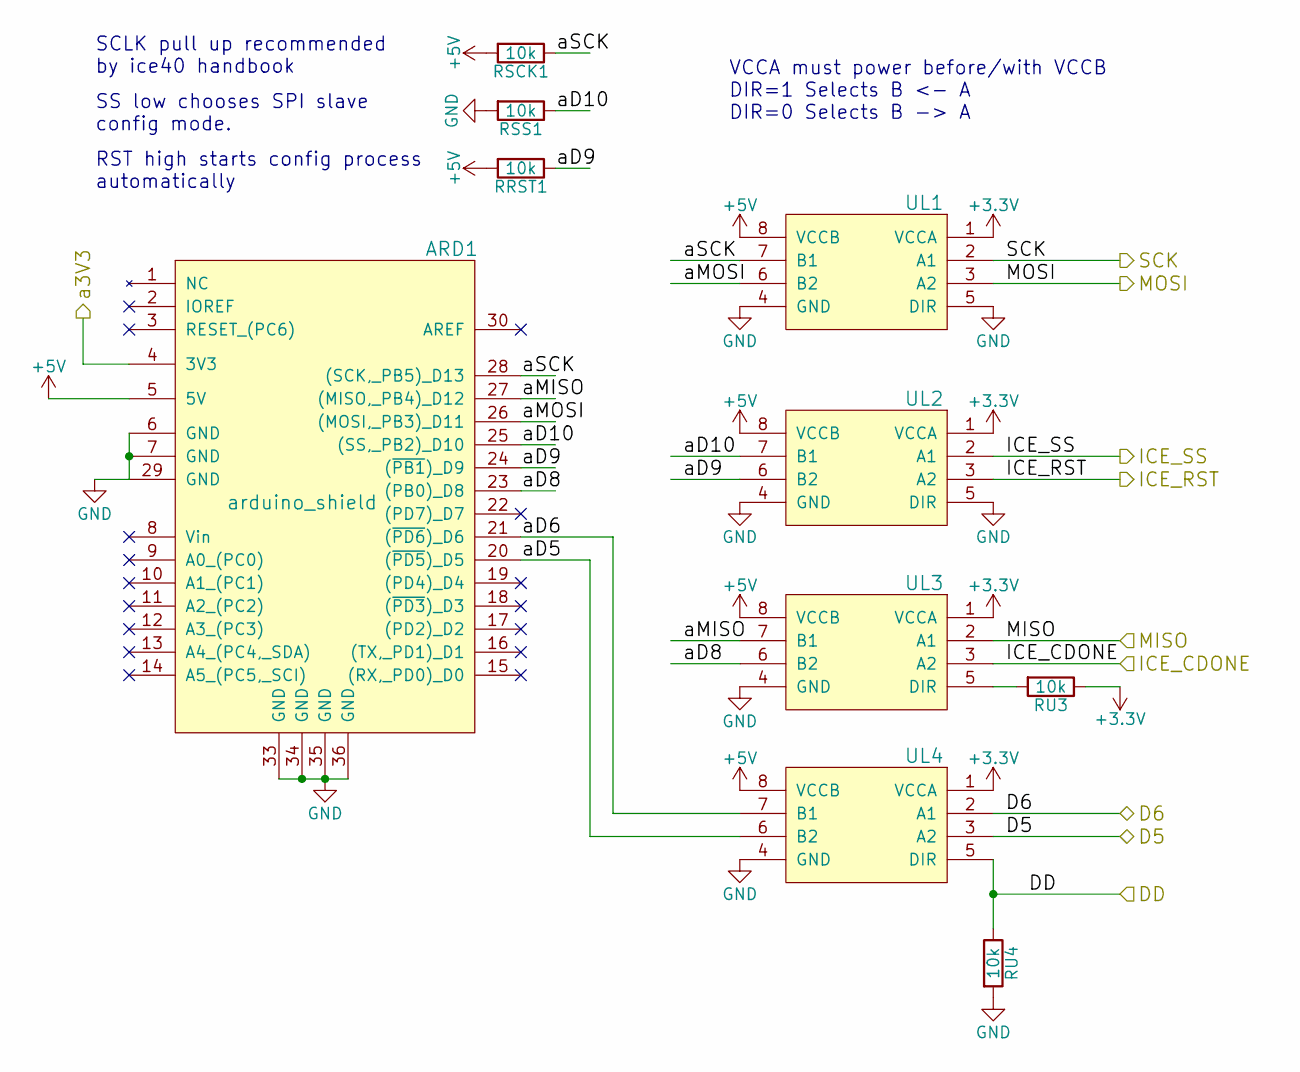
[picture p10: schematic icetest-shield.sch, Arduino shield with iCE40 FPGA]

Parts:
ARD1: arduino_shield
RRST1: 10k; R_0603_HandSoldering
RSCK1: 10k; R_0603_HandSoldering
RSS1: 10k; R_0603_HandSoldering
RU3, RU4: 10k; R_0603_HandSoldering
UL1, UL2, UL3, UL4: sn74lvc2t45; VSSOP-8

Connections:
+3V3: RU3.1, UL1.1 (VCCA), UL2.1 (VCCA), UL3.1 (VCCA), UL4.1 (VCCA); also elsewhere on the board
+5V: ARD1.5 (5V), RRST1.2, RSCK1.2, UL1.8 (VCCB), UL2.8 (VCCB), UL3.8 (VCCB), UL4.8 (VCCB); also elsewhere on the board
/Arduino Shield/D5: UL4.3 (A2); also elsewhere on the board
/Arduino Shield/D6: UL4.2 (A1); also elsewhere on the board
/Arduino Shield/DD: RU4.1, UL4.5 (DIR); also elsewhere on the board
/Arduino Shield/ICE_CDONE: UL3.3 (A2); also elsewhere on the board
/Arduino Shield/ICE_RST: UL2.3 (A2); also elsewhere on the board
/Arduino Shield/ICE_SS: UL2.2 (A1); also elsewhere on the board
/Arduino Shield/MISO: UL3.2 (A1); also elsewhere on the board
/Arduino Shield/MOSI: UL1.3 (A2); also elsewhere on the board
/Arduino Shield/SCK: UL1.2 (A1); also elsewhere on the board
/Arduino Shield/a3V3: ARD1.4 (3V3); also elsewhere on the board
/Arduino Shield/aD5: ARD1.20 ((~PD5)_D5), UL4.6 (B2)
/Arduino Shield/aD6: ARD1.21 ((~PD6)_D6), UL4.7 (B1)
/Arduino Shield/aD8: ARD1.23 ((PB0)_D8), UL3.6 (B2)
/Arduino Shield/aD9: ARD1.24 ((~PB1)_D9), RRST1.1, UL2.6 (B2)
/Arduino Shield/aD10: ARD1.25 ((SS,_PB2)_D10), RSS1.1, UL2.7 (B1)
/Arduino Shield/aMISO: ARD1.27 ((MISO,_PB4)_D12), UL3.7 (B1)
/Arduino Shield/aMOSI: ARD1.26 ((MOSI,_PB3)_D11), UL1.6 (B2)
/Arduino Shield/aSCK: ARD1.28 ((SCK,_PB5)_D13), RSCK1.1, UL1.7 (B1)
GND: ARD1.6 (GND), ARD1.7 (GND), ARD1.29 (GND), ARD1.33 (GND), ARD1.34 (GND), ARD1.35 (GND), ARD1.36 (GND), RSS1.2, RU4.2, UL1.4 (GND), UL1.5 (DIR), UL2.4 (GND), UL2.5 (DIR), UL3.4 (GND), UL4.4 (GND); also elsewhere on the board
unnamed: RU3.2, UL3.5 (DIR)

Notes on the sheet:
VCCA must power before/with VCCB DIR=1 Selects B <- A DIR=0 Selects B -> A
SS low chooses SPI slave config mode.
SCLK pull up recommended by ice40 handbook
RST high starts config process automatically

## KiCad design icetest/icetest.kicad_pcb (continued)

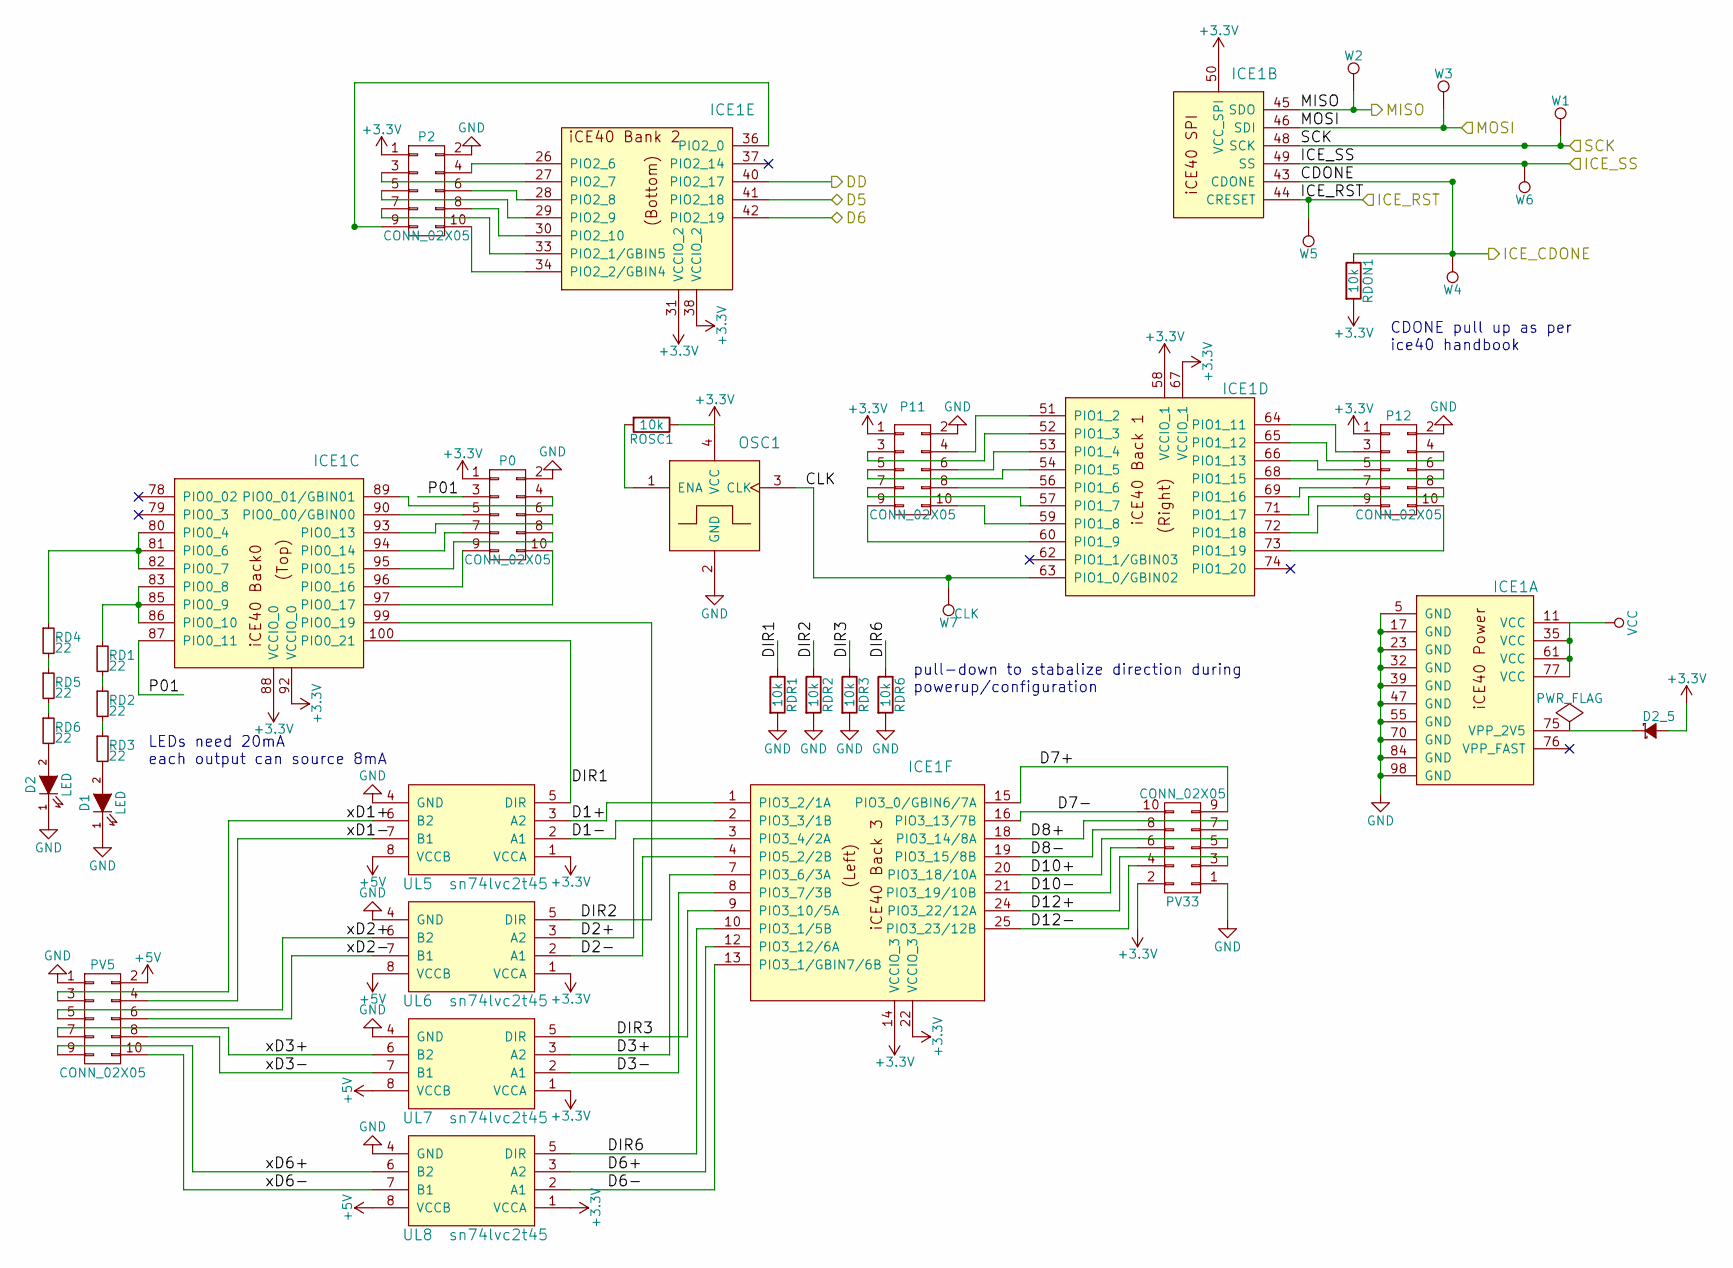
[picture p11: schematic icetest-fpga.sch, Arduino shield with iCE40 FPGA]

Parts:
D1, D2: LED; D_0603_HandSoldering
D2_5: D_Schottky_Small; D_0603_HandSoldering
ICE1: iCE40HX1K-VQ100; VQFP-100
OSC1: oscillator4; OSC_SMD_1
P0, P2, P11, P12: CONN_02X05; Pin_Header_Straight_2x05
PV5, PV33: CONN_02X05; Pin_Header_Straight_2x05
RD1, RD2, RD3, RD4, RD5, RD6: 22; R_0603_HandSoldering
RDON1: 10k; R_0603_HandSoldering
RDR1, RDR2, RDR3, RDR6: 10k; R_0603_HandSoldering
ROSC1: 10k; R_0603_HandSoldering
UL5, UL6, UL7, UL8: sn74lvc2t45; VSSOP-8
W1: SCLK; Measurement_Point_Square-SMD-Pad_Small
W2: MISO; Measurement_Point_Square-SMD-Pad_Small
W3: MOSI; Measurement_Point_Square-SMD-Pad_Small
W4: CDONE; Measurement_Point_Square-SMD-Pad_Small
W5: RST; Measurement_Point_Square-SMD-Pad_Small
W6: SS; Measurement_Point_Square-SMD-Pad_Small
W7: CLK; Measurement_Point_Square-SMD-Pad_Small

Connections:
+3V3: D2_5.2 (A), ICE1.14 (VCCIO_3), ICE1.22 (VCCIO_3), ICE1.31 (VCCIO_2), ICE1.38 (VCCIO_2), ICE1.50 (VCC_SPI), ICE1.58 (VCCIO_1), ICE1.67 (VCCIO_1), ICE1.88 (VCCIO_0), ICE1.92 (VCCIO_0), OSC1.4 (VCC), P0.1, P2.1, P11.1, P12.1, PV33.2, RDON1.2, ROSC1.1, UL5.1 (VCCA), UL6.1 (VCCA), UL7.1 (VCCA), UL8.1 (VCCA); also elsewhere on the board
+5V: PV5.2, UL5.8 (VCCB), UL6.8 (VCCB), UL7.8 (VCCB), UL8.8 (VCCB); also elsewhere on the board
/Arduino Shield/D5: ICE1.41 (PIO2_18); also elsewhere on the board
/Arduino Shield/D6: ICE1.42 (PIO2_19); also elsewhere on the board
/Arduino Shield/DD: ICE1.40 (PIO2_17); also elsewhere on the board
/Arduino Shield/ICE_CDONE: ICE1.43 (CDONE), RDON1.1, W4.1; also elsewhere on the board
/Arduino Shield/ICE_RST: ICE1.44 (CRESET), W5.1; also elsewhere on the board
/Arduino Shield/ICE_SS: ICE1.49 (SS), W6.1; also elsewhere on the board
/Arduino Shield/MISO: ICE1.45 (SDO), W2.1; also elsewhere on the board
/Arduino Shield/MOSI: ICE1.46 (SDI), W3.1; also elsewhere on the board
/Arduino Shield/SCK: ICE1.48 (SCK), W1.1; also elsewhere on the board
/FPGA/CLK: ICE1.63 (PIO1_0/GBIN02), OSC1.3 (CLK), W7.1
/FPGA/D1+: ICE1.1 (PIO3_2/1A), UL5.3 (A2)
/FPGA/D1-: ICE1.2 (PIO3_3/1B), UL5.2 (A1)
/FPGA/D2+: ICE1.3 (PIO3_4/2A), UL6.3 (A2)
/FPGA/D2-: ICE1.4 (PIO5_2/2B), UL6.2 (A1)
/FPGA/D3+: ICE1.7 (PIO3_6/3A), UL7.3 (A2)
/FPGA/D3-: ICE1.8 (PIO3_7/3B), UL7.2 (A1)
/FPGA/D6+: ICE1.12 (PIO3_12/6A), UL8.3 (A2)
/FPGA/D6-: ICE1.13 (PIO3_1/GBIN7/6B), UL8.2 (A1)
/FPGA/D7+: ICE1.15 (PIO3_0/GBIN6/7A), PV33.9
/FPGA/D7-: ICE1.16 (PIO3_13/7B), PV33.10
/FPGA/D8+: ICE1.18 (PIO3_14/8A), PV33.7
/FPGA/D8-: ICE1.19 (PIO3_15/8B), PV33.8
/FPGA/D10+: ICE1.20 (PIO3_18/10A), PV33.5
/FPGA/D10-: ICE1.21 (PIO3_19/10B), PV33.6
/FPGA/D12+: ICE1.24 (PIO3_22/12A), PV33.3
/FPGA/D12-: ICE1.25 (PIO3_23/12B), PV33.4
/FPGA/DIR1: ICE1.100 (PIO0_21), RDR1.1, UL5.5 (DIR)
/FPGA/DIR2: ICE1.99 (PIO0_19), RDR2.1, UL6.5 (DIR)
/FPGA/DIR3: ICE1.9 (PIO3_10/5A), RDR3.1, UL7.5 (DIR)
/FPGA/DIR6: ICE1.10 (PIO3_1/5B), RDR6.1, UL8.5 (DIR)
/FPGA/P01: ICE1.87 (PIO0_11), P0.3
/FPGA/xD1+: PV5.3, UL5.6 (B2)
/FPGA/xD1-: PV5.4, UL5.7 (B1)
/FPGA/xD2+: PV5.5, UL6.6 (B2)
/FPGA/xD2-: PV5.6, UL6.7 (B1)
/FPGA/xD3+: PV5.7, UL7.6 (B2)
/FPGA/xD3-: PV5.8, UL7.7 (B1)
/FPGA/xD6+: PV5.9, UL8.6 (B2)
/FPGA/xD6-: PV5.10, UL8.7 (B1)
GND: D1.1 (K), D2.1 (K), ICE1.5 (GND), ICE1.17 (GND), ICE1.23 (GND), ICE1.32 (GND), ICE1.39 (GND), ICE1.47 (GND), ICE1.55 (GND), ICE1.70 (GND), ICE1.84 (GND), ICE1.98 (GND), OSC1.2 (GND), P0.2, P2.2, P11.2, P12.2, PV5.1, PV33.1, RDR1.2, RDR2.2, RDR3.2, RDR6.2, UL5.4 (GND), UL6.4 (GND), UL7.4 (GND), UL8.4 (GND); also elsewhere on the board
unnamed: D1.2 (A), RD3.2
unnamed: D2.2 (A), RD6.2
unnamed: D2_5.1 (K), ICE1.75 (VPP_2V5)
unnamed: ICE1.26 (PIO2_6), P2.4
unnamed: ICE1.27 (PIO2_7), P2.3
unnamed: ICE1.28 (PIO2_8), P2.6
unnamed: ICE1.29 (PIO2_9), P2.5
unnamed: ICE1.30 (PIO2_10), P2.8
unnamed: ICE1.33 (PIO2_1/GBIN5), P2.7
unnamed: ICE1.34 (PIO2_2/GBIN4), P2.10
unnamed: ICE1.36 (PIO2_0), P2.9
unnamed: ICE1.51 (PIO1_2), P11.4
unnamed: ICE1.52 (PIO1_3), P11.3
unnamed: ICE1.53 (PIO1_4), P11.6
unnamed: ICE1.54 (PIO1_5), P11.5
unnamed: ICE1.56 (PIO1_6), P11.8
unnamed: ICE1.57 (PIO1_7), P11.7
unnamed: ICE1.59 (PIO1_8), P11.10
unnamed: ICE1.60 (PIO1_9), P11.9
unnamed: ICE1.64 (PIO1_11), P12.3
unnamed: ICE1.65 (PIO1_12), P12.4
unnamed: ICE1.66 (PIO1_13), P12.5
unnamed: ICE1.68 (PIO1_15), P12.6
unnamed: ICE1.69 (PIO1_16), P12.7
unnamed: ICE1.71 (PIO1_17), P12.8
unnamed: ICE1.72 (PIO1_18), P12.9
unnamed: ICE1.73 (PIO1_19), P12.10
unnamed: ICE1.80 (PIO0_4), ICE1.81 (PIO0_6), ICE1.82 (PIO0_7), RD4.1
unnamed: ICE1.83 (PIO0_8), ICE1.85 (PIO0_9), ICE1.86 (PIO0_10), RD1.1
unnamed: ICE1.89 (PIO0_01/GBIN01), P0.4
unnamed: ICE1.90 (PIO0_00/GBIN00), P0.5
unnamed: ICE1.93 (PIO0_13), P0.6
unnamed: ICE1.94 (PIO0_14), P0.7
unnamed: ICE1.95 (PIO0_15), P0.8
unnamed: ICE1.96 (PIO0_16), P0.9
unnamed: ICE1.97 (PIO0_17), P0.10
unnamed: OSC1.1 (ENA), ROSC1.2
unnamed: RD1.2, RD2.1
unnamed: RD2.2, RD3.1
unnamed: RD4.2, RD5.1
unnamed: RD5.2, RD6.1
VCC: ICE1.11 (VCC), ICE1.35 (VCC), ICE1.61 (VCC), ICE1.77 (VCC); also elsewhere on the board

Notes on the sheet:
LEDs need 20mA each output can source 8mA
CDONE pull up as per ice40 handbook
pull-down to stabalize direction during powerup/configuration

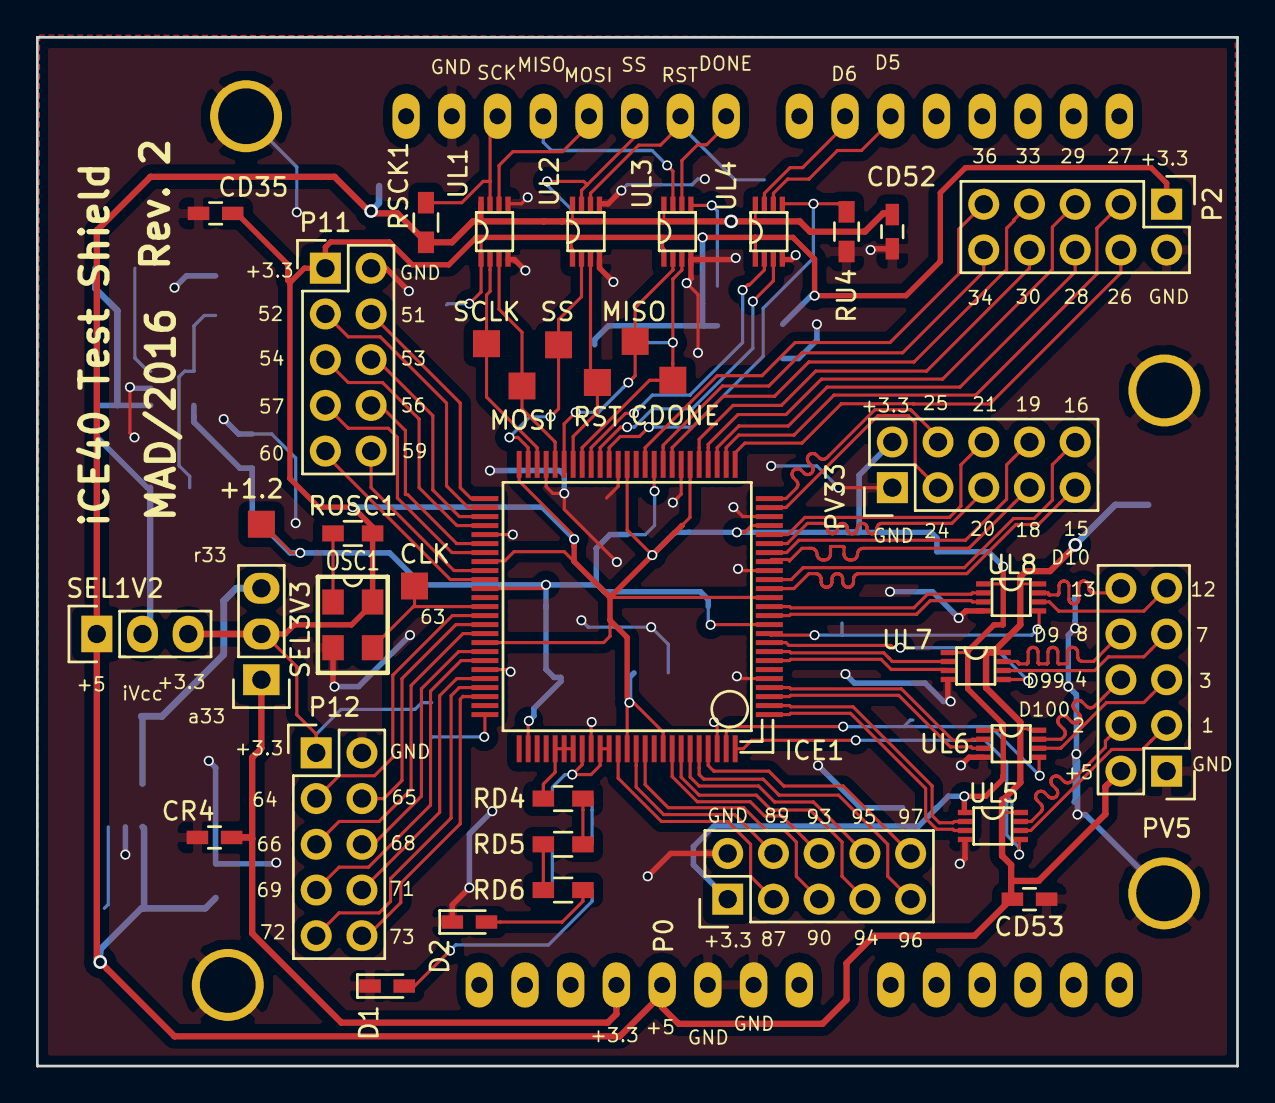
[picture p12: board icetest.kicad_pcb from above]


Board: 2 copper layers, 66.7 x 57.2 mm, 74 parts (35 on the bottom side), 99 nets.

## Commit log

2016-07-23 add SPI test points and verify footprints
    [icetest-fpga.sch, icetest-shield.sch, icetest.kicad_pcb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]
2016-07-23 route it
    [icetest-shield.sch, icetest.kicad_pcb]
2016-08-02 fix ard symbol and route
    [icetest-fpga.sch, icetest-shield.sch, icetest.kicad_pcb]
2016-08-02 remove dup pins from symbols
    [icetest-fpga.sch, icetest.kicad_pcb]
2016-08-06 fix schematic bugs
    signal on N/C pin on ice40
    1.2V regulator R divider moved to input side
    Remove R divider for 3.3V (not needed for fixed V model)
    [icetest-fpga.sch, icetest-shield.sch, icetest.sch]
2016-08-07 update layout
    [icetest.kicad_pcb]
2016-08-07 add LED2 and update layout
    [icetest-fpga.sch, icetest.kicad_pcb]
2016-08-07 clean and oshpart rules
    [icetest-fpga.sch, icetest.kicad_pcb, icetest.sch]
2016-08-07 scripts to generate and view gerbers
2016-08-07 fix solder mask gap and others
    [icetest.kicad_pcb]
2016-08-07 more current for LEDs
    [icetest-fpga.sch, icetest.kicad_pcb]
2016-08-08 minor layout
    [icetest-fpga.sch, icetest-shield.sch, icetest.kicad_pcb]
2016-08-08 add schematic notes
    [icetest-fpga.sch, icetest.sch]
2016-10-08 add errata and notes
    [icetest.kicad_pcb]
2016-10-09 switch level shifter
    [icetest-fpga.sch, icetest-shield.sch, icetest.sch]
2016-10-10 redo layout
    [icetest-fpga.sch, icetest-shield.sch, icetest.kicad_pcb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]
2016-10-10 more layout
    [icetest-fpga.sch, icetest-shield.sch, icetest.kicad_pcb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]
2016-10-15 bom generation
2016-11-06 move to sub-dir
    [icetest-fpga.sch, icetest-parts.csv, icetest-shield.sch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]
2016-12-05 start utherm
    [utherm.kicad_pcb, utherm.sch]
2016-12-18 add opamp breakout
    [opfun.kicad_pcb, opfun.sch]
2016-12-25 start icedaq
    [icedaq-analog.sch, icedaq.kicad_pcb, icedaq.sch]
2017-08-13 icedaq: update
    [icedaq-analog.sch, icedaq.kicad_pcb, icedaq.sch]
2017-08-13 icedaq layout
    [icedaq-analog.sch, icedaq.kicad_pcb, icedaq.sch]
2017-08-13 icedaq more
    [icedaq-analog.sch, icedaq.kicad_pcb, icedaq.sch]
2017-08-20 icedaq: change input filter
    [icedaq-analog.sch, icedaq.kicad_pcb]
2017-08-22 icedaq: layout take 2
    [icedaq-analog.sch, icedaq.kicad_pcb, icedaq.sch]
2017-08-23 icedaq: relocate connectors
    [icedaq-analog.sch, icedaq.kicad_pcb, icedaq.sch]
2017-08-23 icedaq rev 1
    [icedaq-analog.sch, icedaq.kicad_pcb, icedaq.sch]
